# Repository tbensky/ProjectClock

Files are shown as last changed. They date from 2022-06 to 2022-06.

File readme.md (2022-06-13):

# Mechanical Clock Escapement

The following directions illustrate a step by step plan to building a working, gravity-driven mechanical clock escapement.

Clock Escapement

([See on Youtube](https://youtube.com/shorts/22PK3F16n6g]))

## Parts

The escapement can be constructed using the parts shown here.

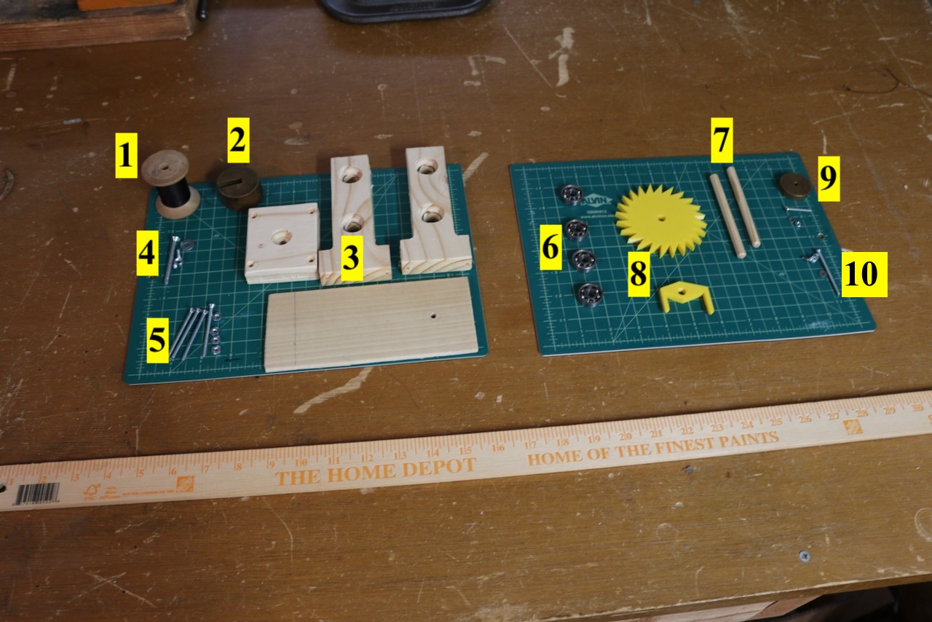
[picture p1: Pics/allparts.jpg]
Parts


1. Some string used for the drive weight.

2. Some weight to drive the escapement. This escapement runs on about 200 g (0.5 lbs) of weight (minimum). Shown is a piece of brass, but anything can be used.

3. Parts cut from some solid material (wood, plastic, composite, etc.); see Frame section below.

4. #10 screw with washer and wing nut.

5. 4, 2" long #6 screws with washers and nuts.

6. 4 fidget spinner bearings.  Outer diameter is 22 mm, inner diameter (of hole) is 8 mm, and thickness is 7 mm. These are very common bearings and sizes. (See Amazon and eBay.)

7. Two 5/16" (7.9 mm) (dia.) wooden dowels cut to 4" long. The dowels should be able to slide into the (8 mm) holes on the bearings.

8. 3D printed escape wheel and anchor (see below).

9. 50 g (0.1 lb) weight to be attached to the swinging end of the pendulum. This helps it keep swinging. Can be anything as long as it has a bit of mass.

10. 1, 2" long #4 screw with washer and wing nut (this is for clamping the pendulum onto the escape wheel axis; see below).

## Frame

To start, you'll have to CNC four parts out of some solid material like wood (manual cutting is possible). Any machinable wood, plastic or composite will work too (like MDF, Delrin, acrylic, etc). The only condition is that your stock is a minimum of 0.28" (7 mm) in thickness.  We used pine (wood) planks used for shelving (from our local hardware store) that are about 0.8" thick. The material serves as the escapement frame, holding everything togetgher. 

The CAD (.DWG file) is in the CAD folder, and looks like this

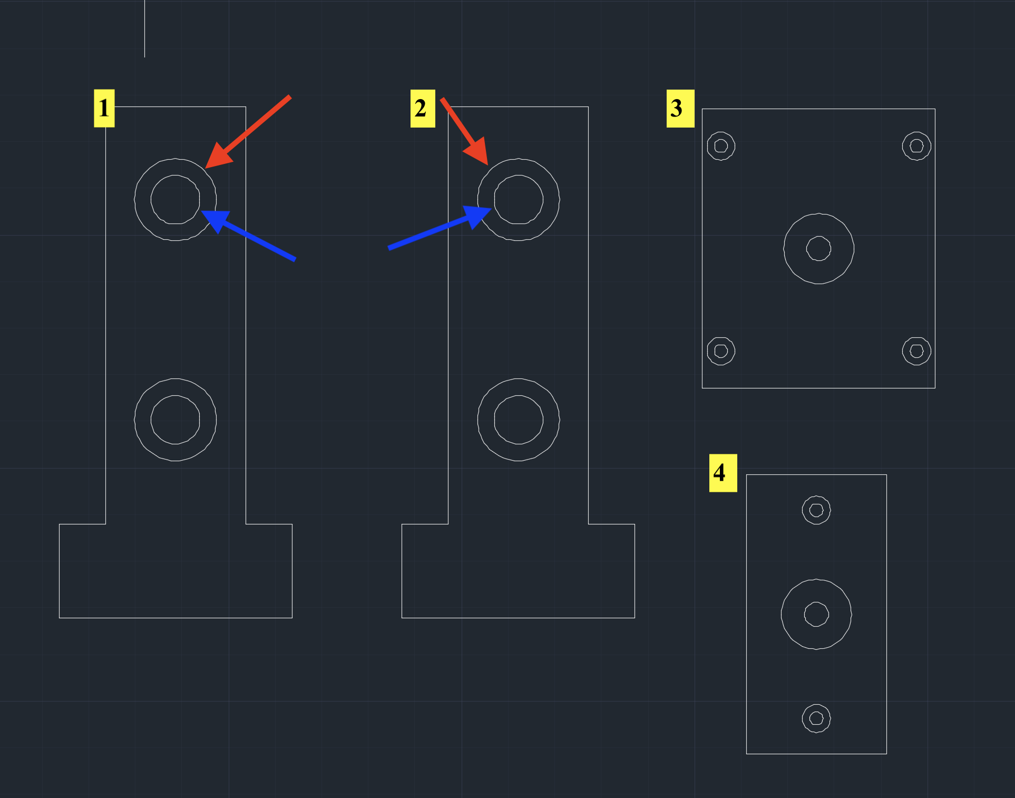
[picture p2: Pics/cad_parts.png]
CAD file


Parts 1 and 2 are the sides of the escapement frame. Part 3 is the base of the frame, and Part 2 is the top of the frame.  The circles pointed to by the red arrows are to be CNCed as "pockets cuts" to 0.2730" (7 mm) deep. The circles with the blue arrows are to be cut through.  The smaller (outer) circles on Parts 3 and 4 are also 0.1" deep pocket cuts, and serve as countersinks for #6 screw heads. The inner circles on Parts 3 and 4 are to be cut through.  The large circles at the center of Parts 3 and 4 are pocket cuts to about 1/2 the depth of your material. These are not critial to the escapement; they are meant to countersink a clamping bolt.  The inner center circles on these pieces are to be cut through.

We get good results using two cutting tools.  All pockets cuts on Parts 1, 2, 3 and 4 and the countersinks and through-holes on Parts 3 and 4 are first cut with a 1/8" end mill. Some precision is needed on the pocket cuts to hold the bearings snugly with just friction (and the 1/8" cutting tool seems to deliver on this). Everything else can be done with a 1/4" end mill. Use tabs on all parts. 

Our CNC simulation looks like this

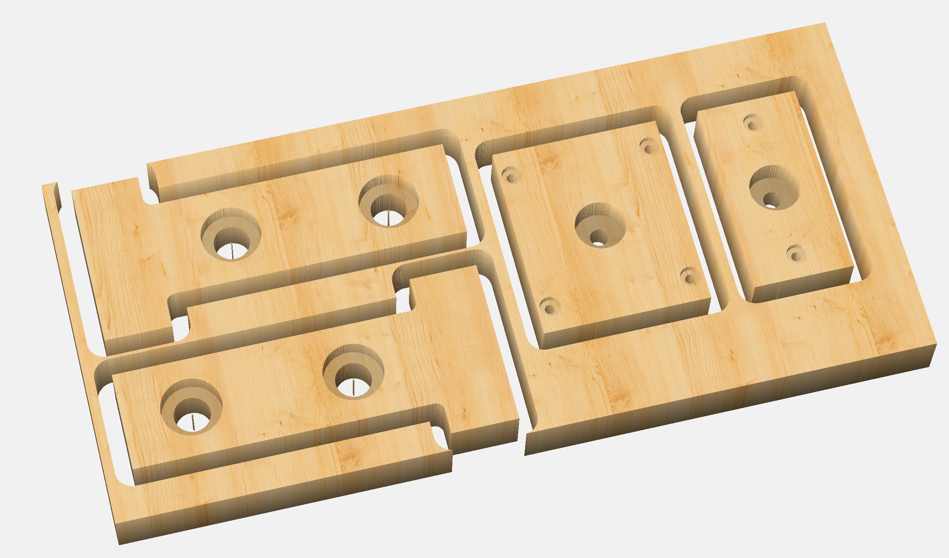
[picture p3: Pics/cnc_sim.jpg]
CNC simulation


We used a Shapeoko CNC from Carbide3D. For efficient material use, we used a 12"x5.5"x0.8" plank. Set the origin to the upper-left and clamps along the long edges of the board.  

### No CNC?

It's possible to make the frame without a CNC machine.  The only real need is to hold two pairs of bearings 2.36" apart center-to-center (+/- 0.01", escapements are finicky).  The bearings are 22 mm in diameter; holes to hold them can be made with an appropriately sized Forestner bit. Some sanding or firming up may be needed.

### Frame assembly

Once the frame pieces are ready, clamp (but do not glue) them together like this

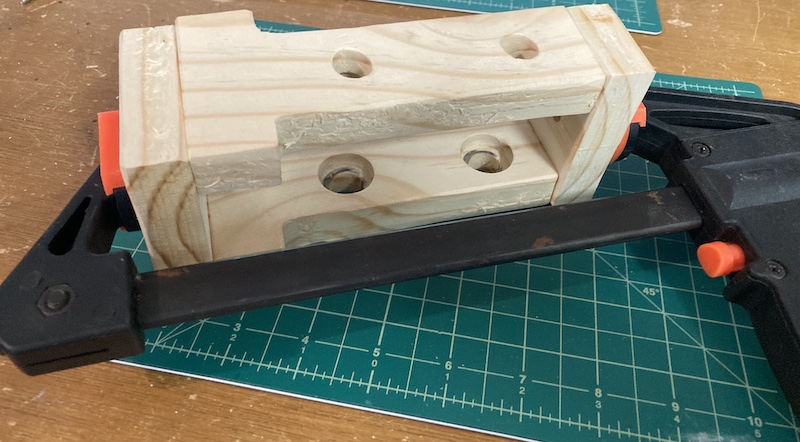
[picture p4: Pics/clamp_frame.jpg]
frame clamp


and be sure everything is squared up.  You are just clamping them here; do not apply any glue.  The pocket cuts that hold the bearings can face either inward or outward.

When secure, drill up through the four holes in the base, from the bottom of the base, up into both of the sides, like this

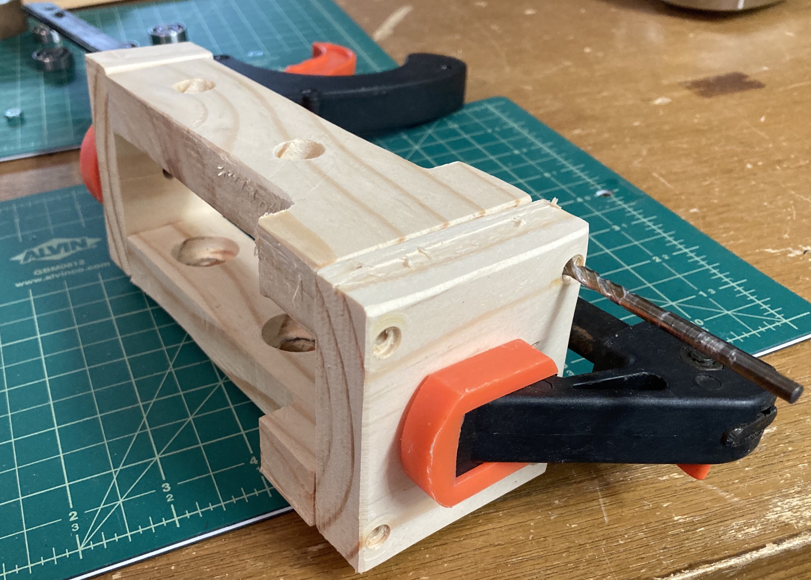
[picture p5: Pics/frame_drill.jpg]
frame clamp


Each hole should be able to accommodate one of the 4 #6 screws. We used a 5/32" drill bit. The screws are meant to hold the sides to the base and should sink nicely into the CNCed countersinks. The top isn't really used or important.  You can attach it to the escapement as a final step if you wish.

##  Escape wheel and anchor

The escape wheel (with 24 teeth) and the anchor look like this (on the way to a 3D printer):

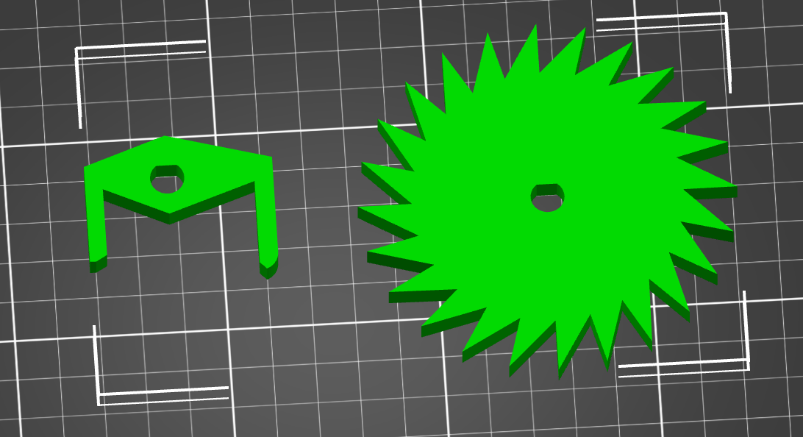
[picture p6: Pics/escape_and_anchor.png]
escape_anchor


We 3d printed these with PLA (STL files for them are in the STL folder), but they can be CNCed as well (see .dwg file in the Cad folder).   If CNCed, they should be cut on 1/4" thick stock. We've used wood, acrylic and Delrin. If anyone cuts them from Aluminum or Brass (or any metal), let us know (we'd love to see it). We recommend a 1/8" endmill.

Here's our 3D printed result.

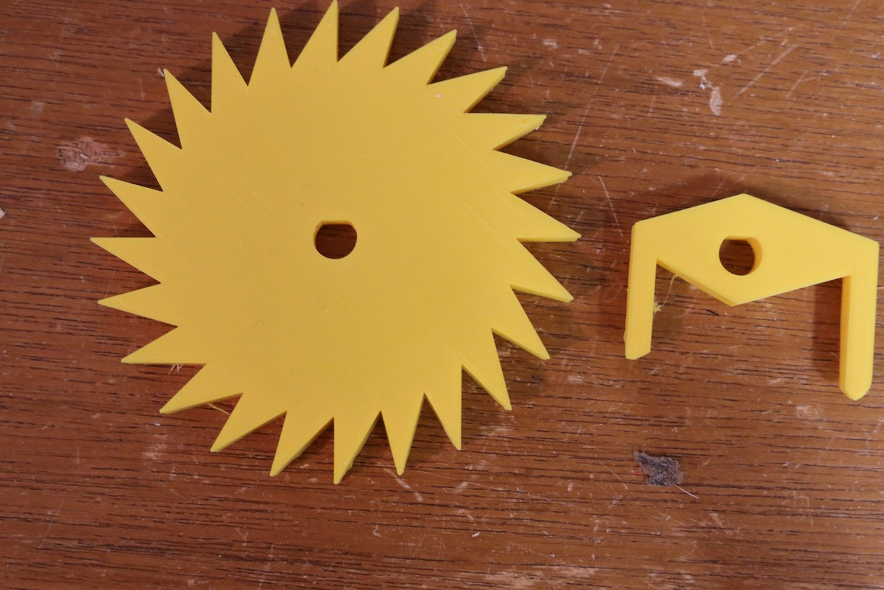
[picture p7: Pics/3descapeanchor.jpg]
escape_and_anchor


### No CNC or 3D printer?

If you trace the pattern onto a 1/4" wooden plank, you can try to cut out the escape wheel and anchor with a scroll saw, but it is difficult to get parts that will work. Escapements are finicky and the 3D printed parts here are good to 0.1 mm or so. With a scroll saw, you'll get the parts, but the escapement may not work no matter how hard you try.  Mounting holes for each can be made with a 7/16" drill bit. 

### Mounting the escape wheel and anchor

The escape wheel and anchor are to be mounted onto the 7/16" x 4" wooden dowels.  As you can tell, the wheel and anchor are keyed, so you'll have to sand down a flat section on the dowels to allow them to fit into the holes on either.  Sand carefully, as this should be a very snug fit. We used Gorilla Glue two-part epoxy to fasten the two.

Important: Do not center the escape wheel or anchor on each's dowel. Place each about 2.5" from either end as shown here. The asymmetry is so you can have the pendulum swing on one side of the escapement, and the weight fall on the other.

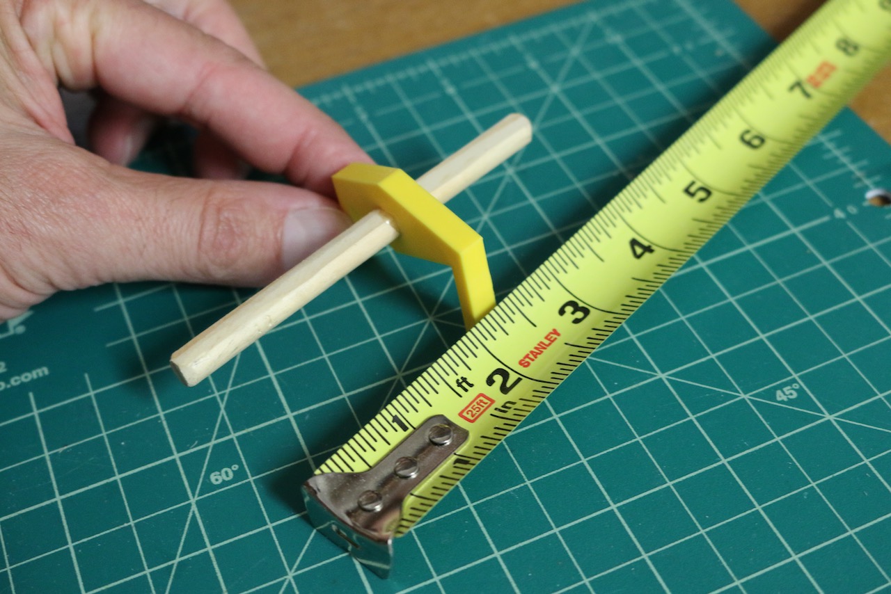
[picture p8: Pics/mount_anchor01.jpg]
escape_and_anchor


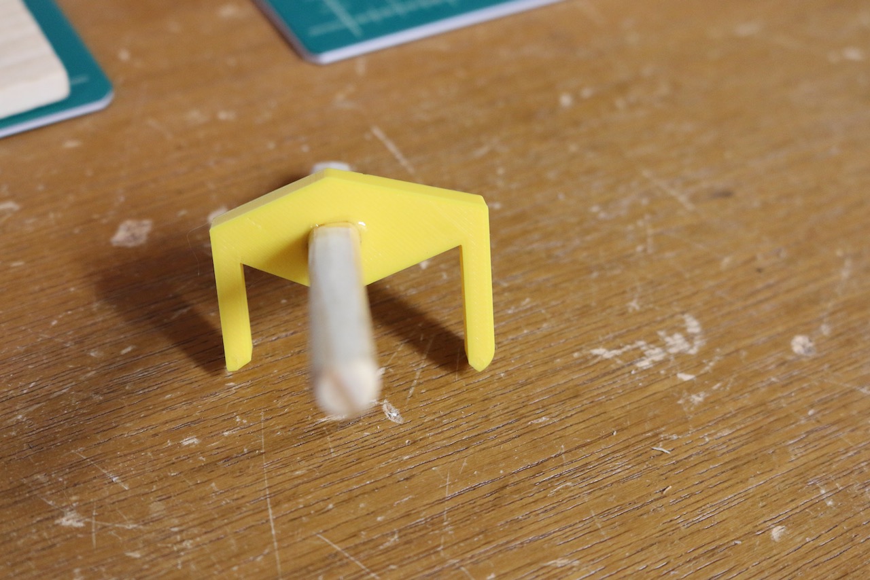
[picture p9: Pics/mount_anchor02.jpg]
escape_and_anchor


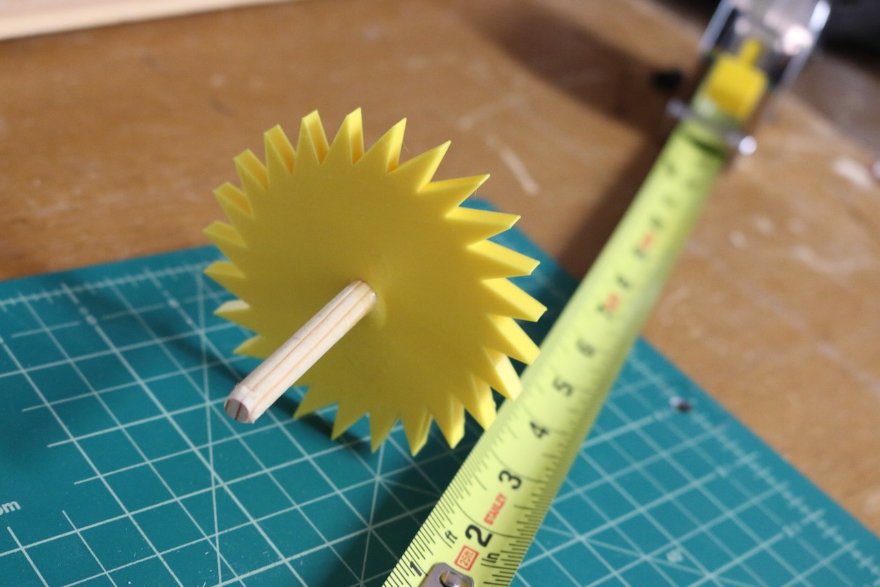
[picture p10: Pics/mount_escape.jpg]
escape_and_anchor


Near the tip of the long end of the dowel holding the escape wheel, drill a small radial hole through the dowel that you can thread a string through. (This will help later when attaching the drive weight.)

## Support

This piece is not critical, but allows for the escapement to be clamped over the end of a table while you're working on it.  

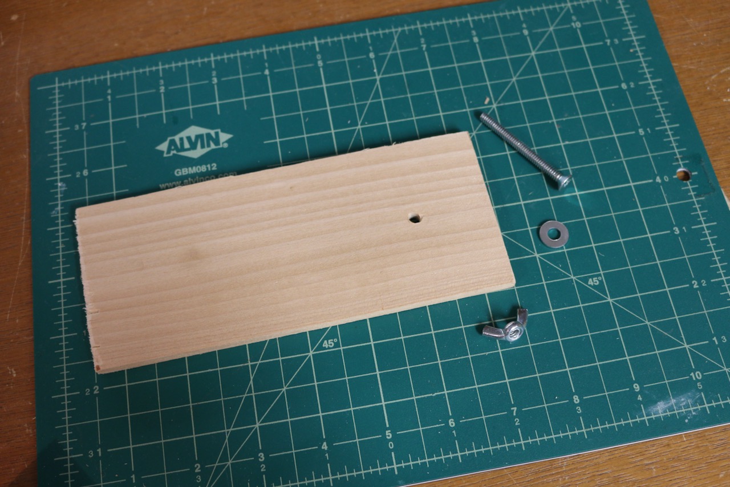
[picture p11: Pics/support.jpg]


We cut a 7"x3" by 1/4" thick piece of scrap and drilled a hole that can accommodate the #10 screw. The hole should be positioned so the thru hole in the wooden base of the escapement can be held at the end of the support by the screw. In use, it'll look like this

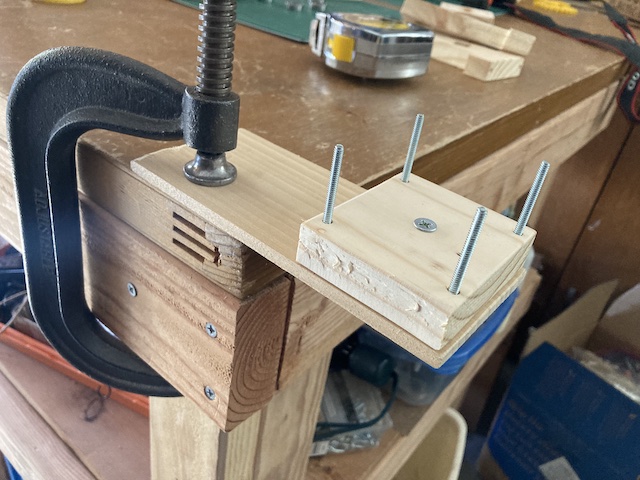
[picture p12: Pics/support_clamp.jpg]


## Pendulum

The pendulum is a yard stick from the hardware store (used for stirring paint). They work well, because they'll give your escapement a period of about 1 second, and tend to stay straight.

To start, on one end, drill a 5/16" hole about 1" from the end. Use a hand saw to cut a slot from the end of the pendulum to the hole itself, then sand the inner edges of the slot a bit
to give it some width, as shown here

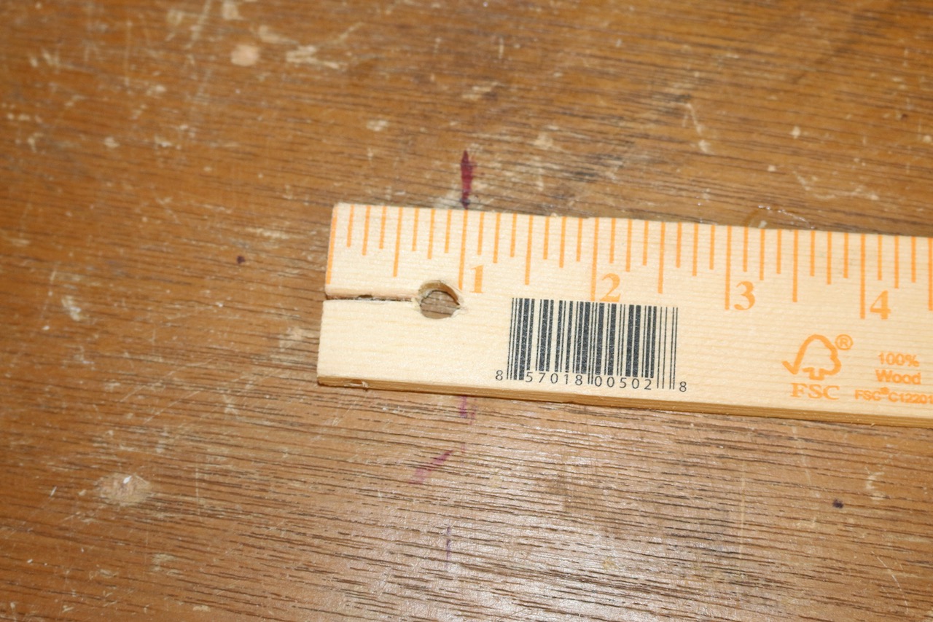
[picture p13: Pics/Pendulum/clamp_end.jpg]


Next, drill a hole suitable for a #4 screw transverse to the slot, like this

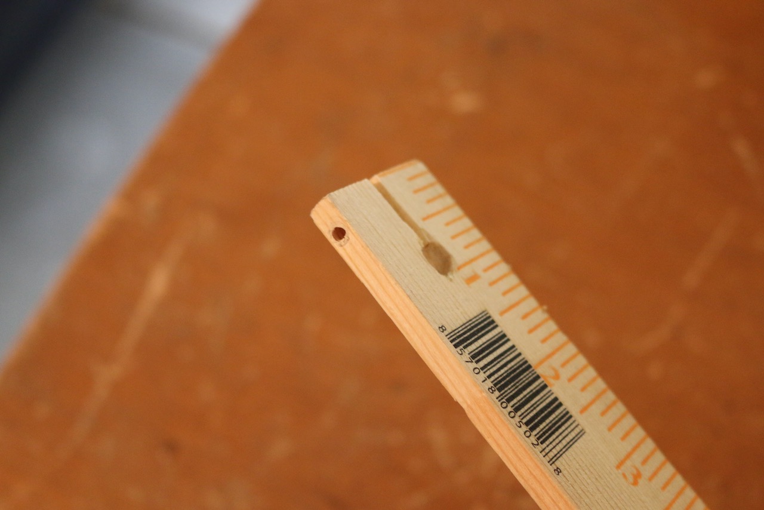
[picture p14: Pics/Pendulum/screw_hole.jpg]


(These steps might be reversed for better results; that is, drill the #4 transverse hole first.)

Next, insert the 2" long #4 screw with its wing nut.

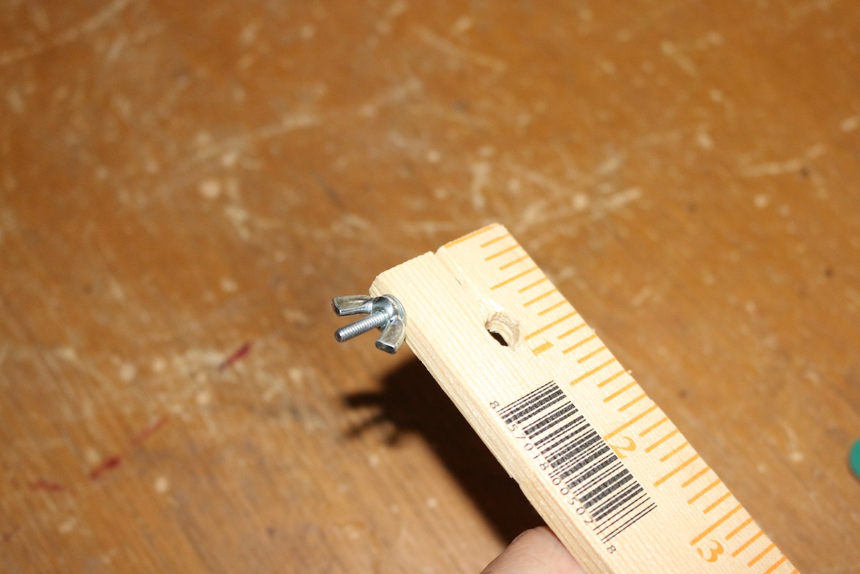
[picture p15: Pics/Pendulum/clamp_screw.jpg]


This will allow you to clamp the pendulum onto the anchor's dowel/axle.

On the other end of the pendulum, drill a hole so you can mount a small weight onto the end of the pedulum. This is not critical (do whatever is needed). Ours looks like this

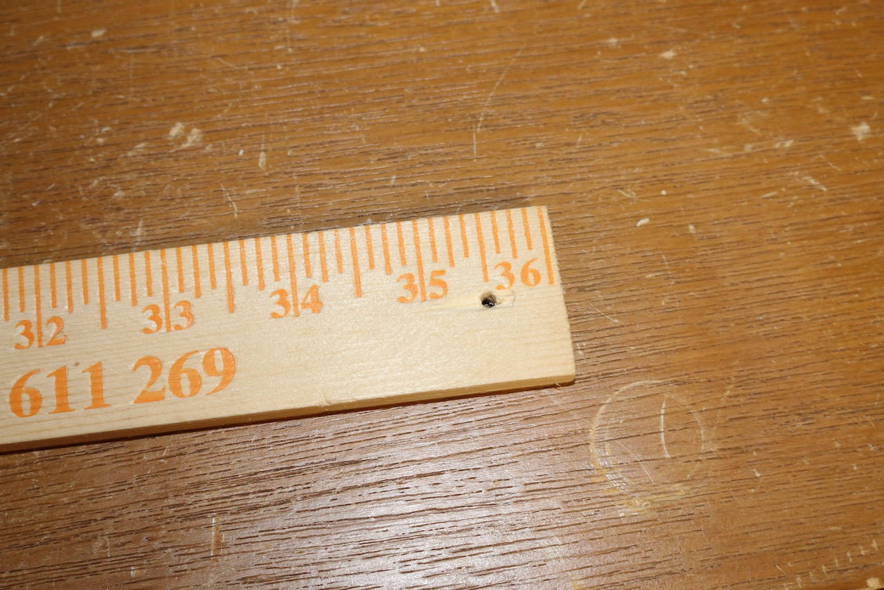
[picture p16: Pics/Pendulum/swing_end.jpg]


and

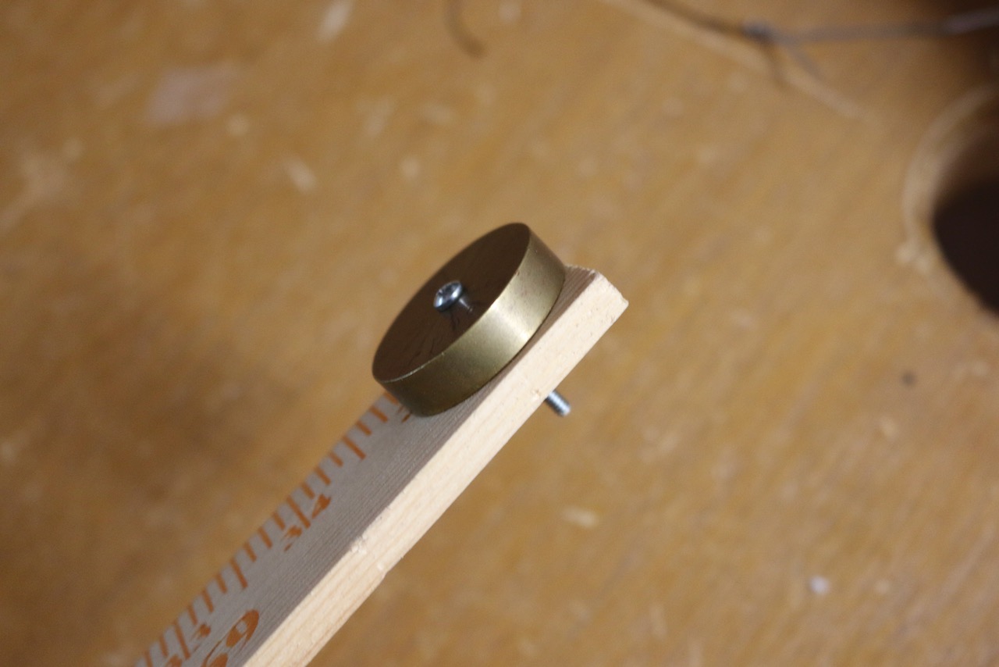
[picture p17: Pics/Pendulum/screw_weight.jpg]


A small stack of washers has also worked for this. The mass at the end of the rod gives the swinging pendulum some good angular momentum, which helps to keep the escapement running. 

# Assembly

Now, push the bearings into the holes on the frame. The bearings should fit snugly, but not too tight. If the bearings are pushed on too much by the wood, they won't turn freely. You should be
able to push them into the frame fairly easily with just your fingers (no hammers or forcing/pounding).

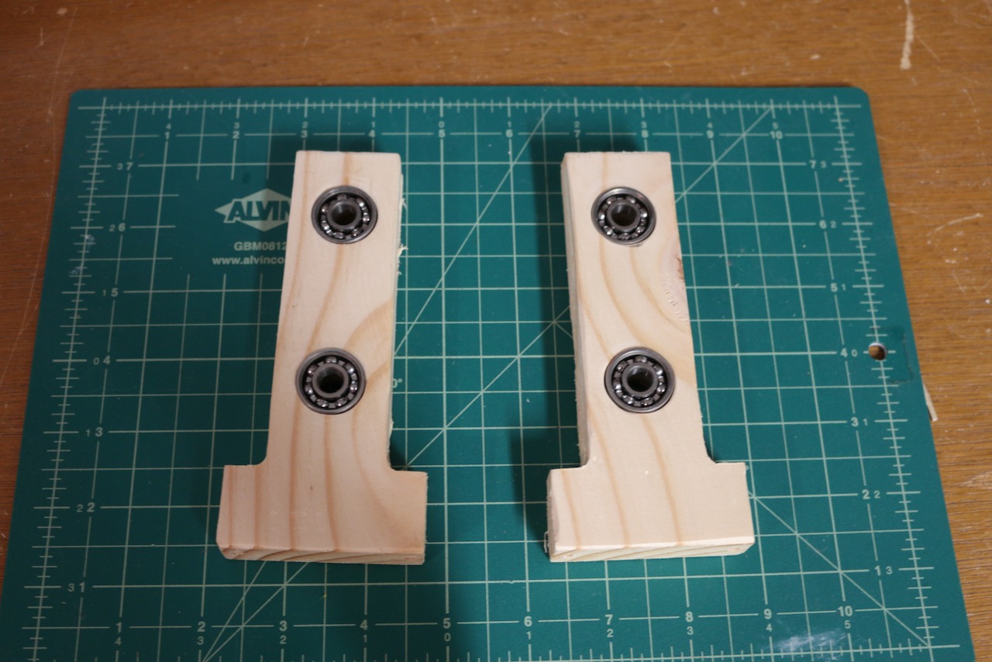
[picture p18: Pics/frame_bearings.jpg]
bearings in frame


Now, juggling everything, work to assemble your parts like this.

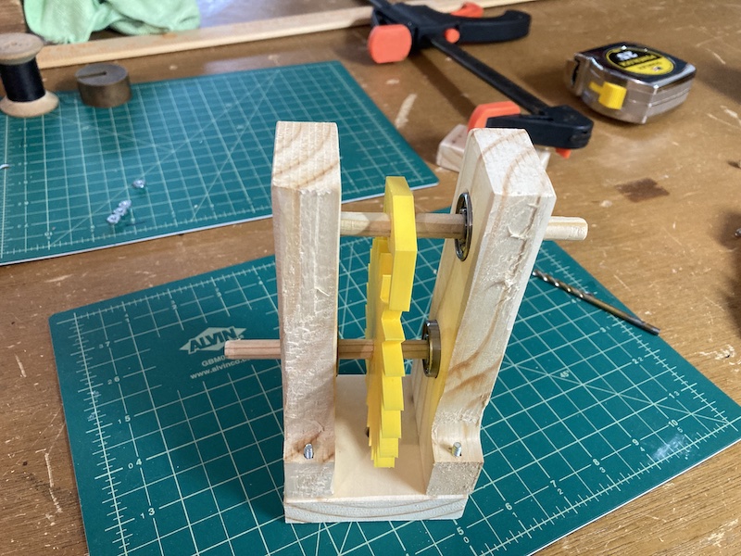
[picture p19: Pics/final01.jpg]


The anchor and escape wheel should overlap horizontally.  Also, be sure the longer end of the anchor goes out one side, and the longer end of the escape wheel goes out the other.

You can now mount the assembly on the support board, fastening it with the #10 screw and wing nut.  Clamp it to a table so the escapement is over the edge like this.

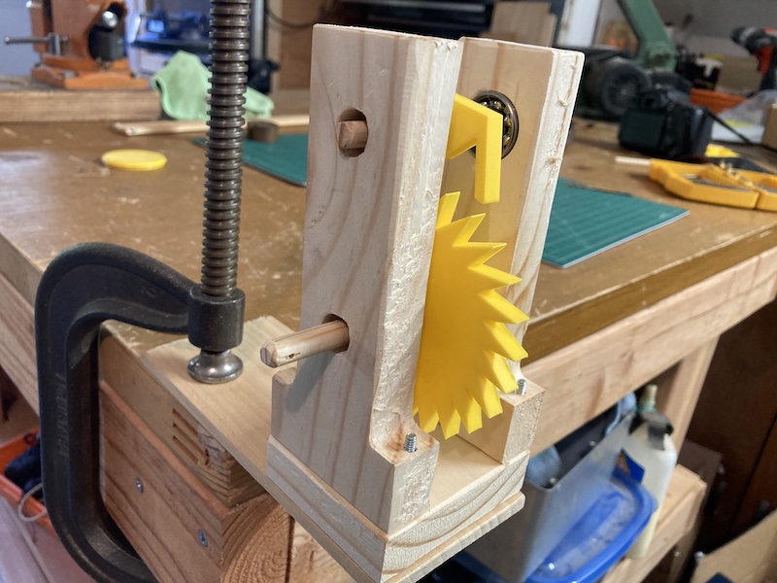
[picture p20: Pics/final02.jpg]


Put the nuts onto the #6 screws, to tighten the base to the sides of the escapement.

# Quick escapement tutorial

You're about ready to install the pendulum and drive weight and get your escapement running. Before that, let's take a quick look at how escapements are supposed to work.

First, the anchor and escape wheel need to be able to come into contact with one another. Further, the amount of contact they have and when they contact are somewhat critical. The shape
of both the anchor and escape wheel are important as well.

This animation from [here](https://en.wikipedia.org/wiki/Escapement) is very helpful and instructive

esccapement

Watch it for a while and see how the anchor and escape wheel teeth interact. We need to reproduce some of this action here.

In this figure, our anchor and escape wheel in close proximity. (As you look through these figures, note that for this escapement, the escape wheel always rotates clockwise due to the drive weight, and the anchor will always oscillate back and forth.)

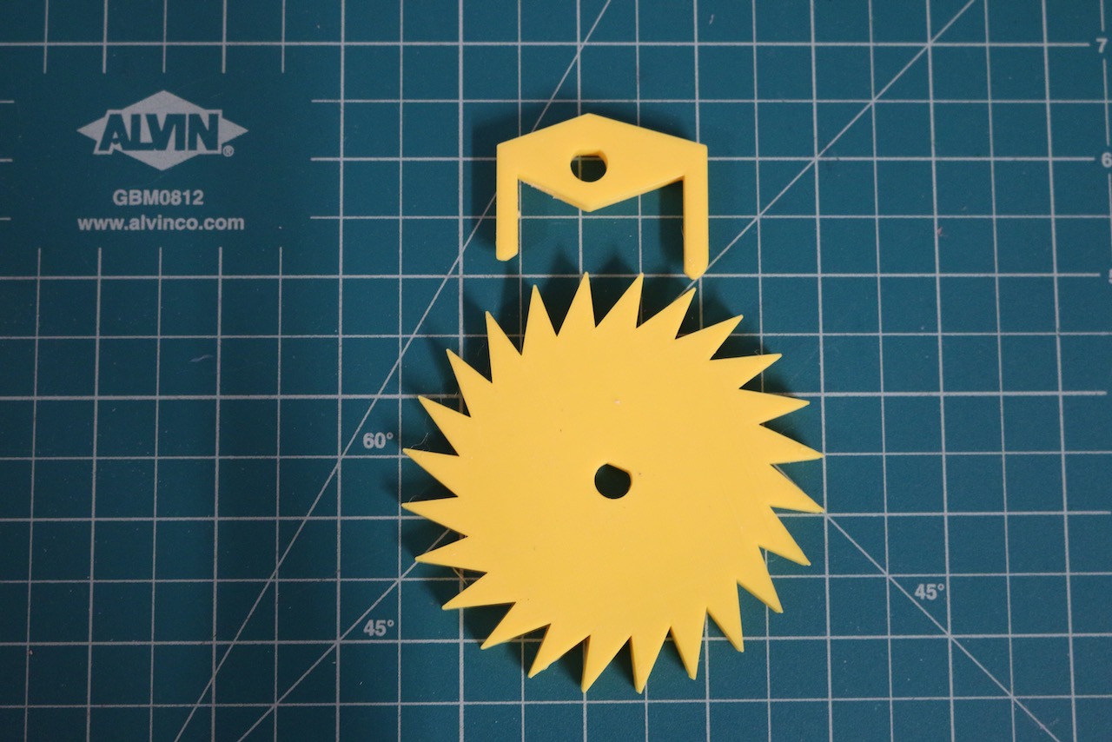
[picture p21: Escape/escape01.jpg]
escapement


But the escape wheel to anchor distance is too far apart for any working escapement. You'd have to have a very large pendulum swing angle to get the anchor's pallets to engage with the escape wheel.

Let's lower the anchor some like this

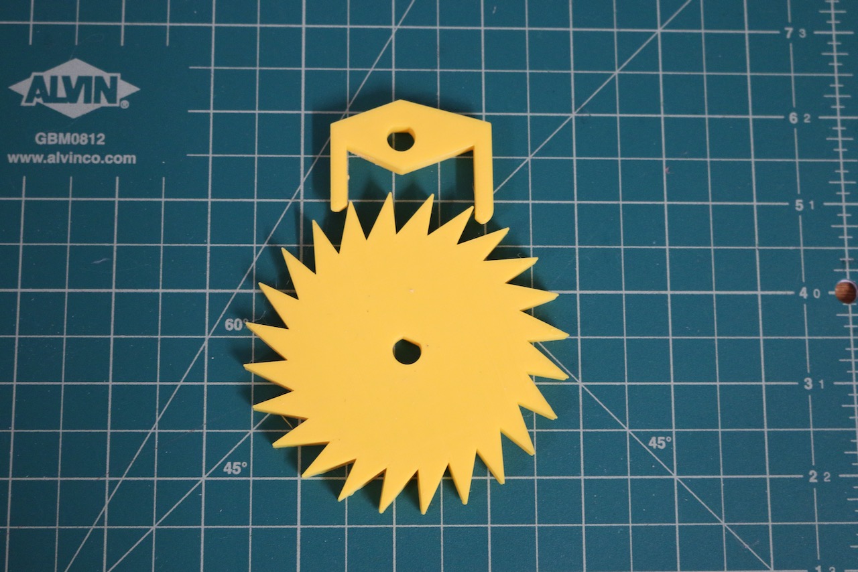
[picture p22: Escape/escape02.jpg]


Now, imagine the anchor oscillating (as driven by the pendulum), like this

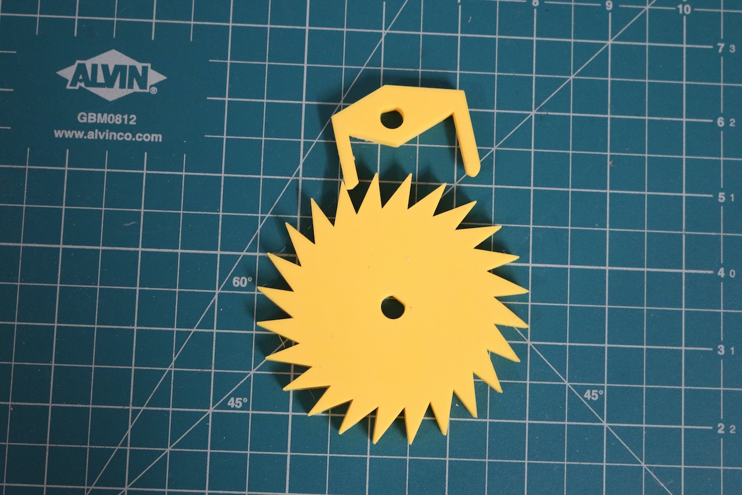
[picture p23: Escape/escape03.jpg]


See the contact? This stops the escape wheel from spinning. The sound of the contact will be a "tick" for the clock.

Then back again.

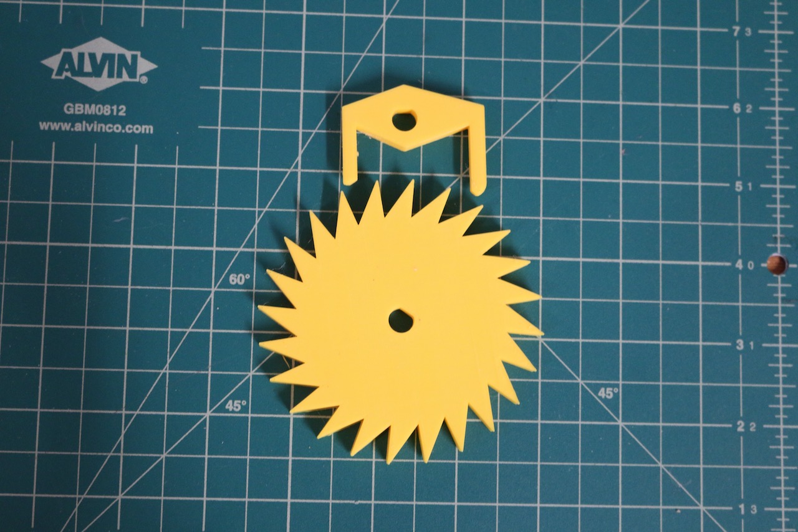
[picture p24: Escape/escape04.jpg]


Here there is no contact and the escape wheel is free to spin (but it won't get very far) because very soon, contact is made again like this:

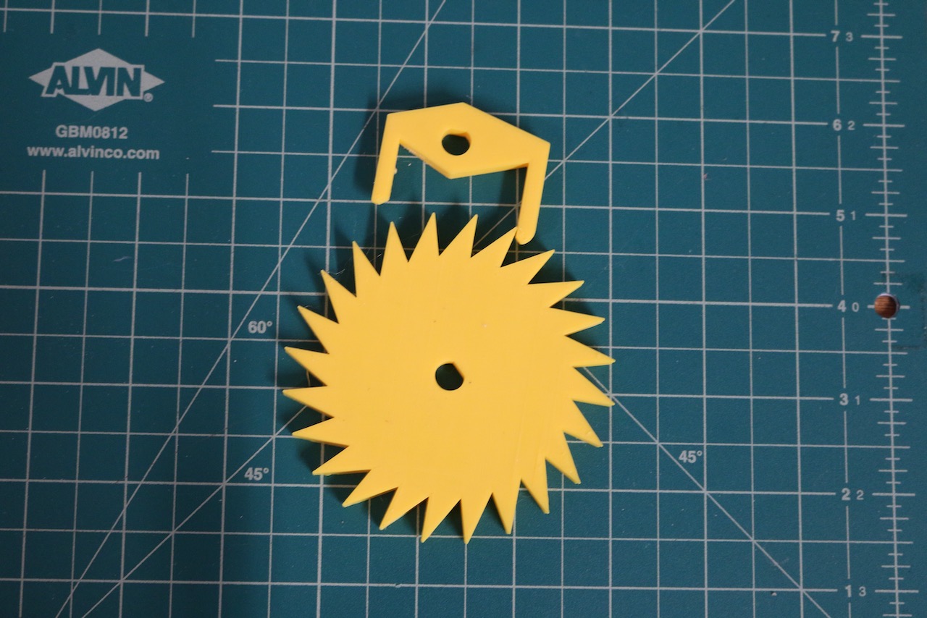
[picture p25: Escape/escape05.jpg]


This will once again stop the escape wheel again and make the "tock" sound.

It is difficult to design an escapement.  It is not enough to simply periodically stop the escape wheel. The pallets have to be shaped so that the releases (after the contact) can give the pendulum a knudge by the escape wheel with each release. This puts a bit of energy into the pendulum, to keep it swinging.

Here, by trial and error, with adjusting surfaces to $\approx 1$ mm, you can see how the escape wheel tooth slides off of the anchor, in a way that gives a little kick
to the pendulum.

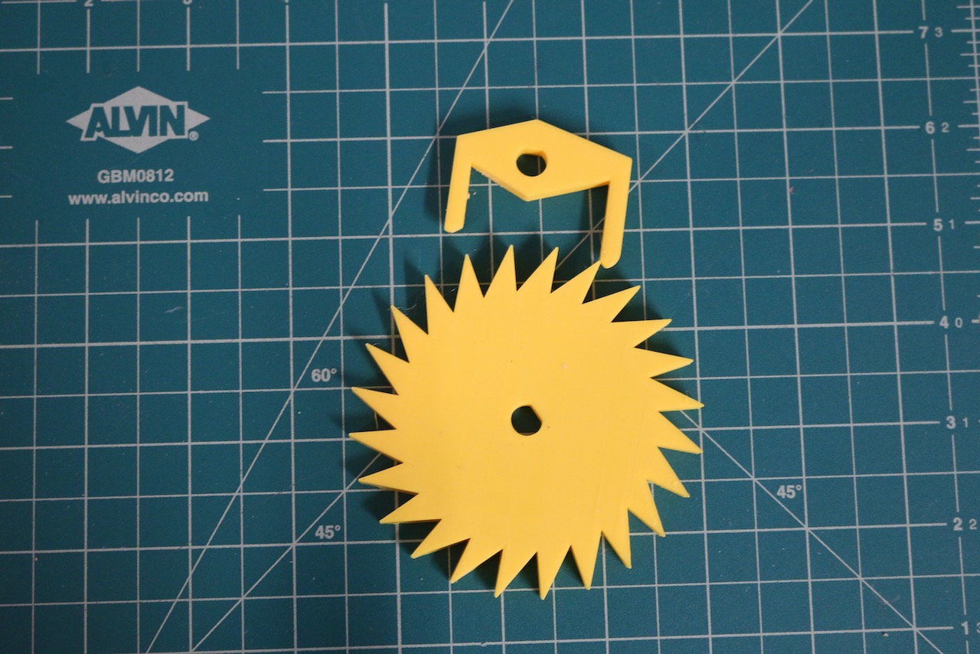
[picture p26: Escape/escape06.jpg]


When the left pallet of the anchor hits the escape wheel, it's a dead stop, with very little energy transfer back to the pendulum.  The right pallet however, after it stops the crown wheel, allows the tooth to slide off of it, along its contours to impart some energy into the pendulum. There are infinite variations of this, and it's quite interesting to study. (If you ever make it to London, England, there are 100s of escapements to watch in local museums.)  

The escapement here was developed by painstakingly watching non-working anchors (we made) for places where they jam up, stopping the escapement. When found, some CAD work and refabrication was done to reshape the anchor's surface to remove such jam points. The anchor design here is one that finally worked.

In this escapement, all of the distances and sizes are workable. That is, the bearing center-to-center distances (the 2.36" above), and the shapes of the escape wheel and anchor are all tied together. If for example, the bearing to bearing distance is too large or small, the anchor may not engage the crown wheel properly. Thus, this escapement design is reduced down to only one possible adjustment (see below).

# Installing the pendulum and drive weight

You are now ready to install the pendulum and drive weight.

First the pendulum, which just slides and clamps onto the axle of the anchor. Get it snug for now, but do not tighten the clamp screw.

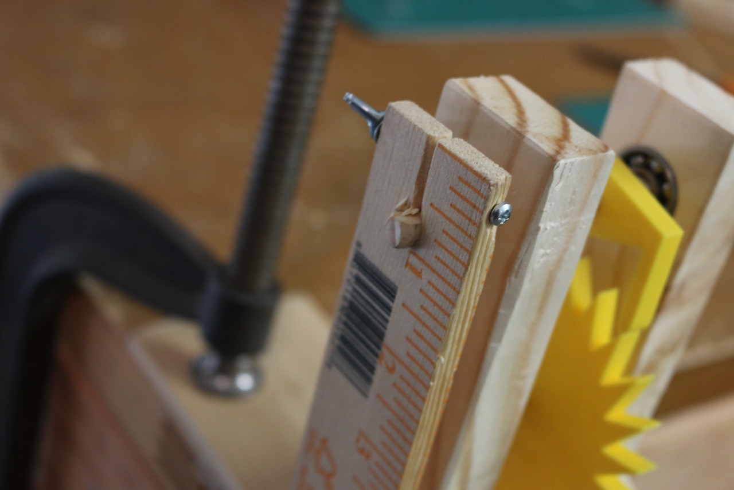
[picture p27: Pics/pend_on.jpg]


Next, tie some string through the hole on the end of the escape wheel's axle.

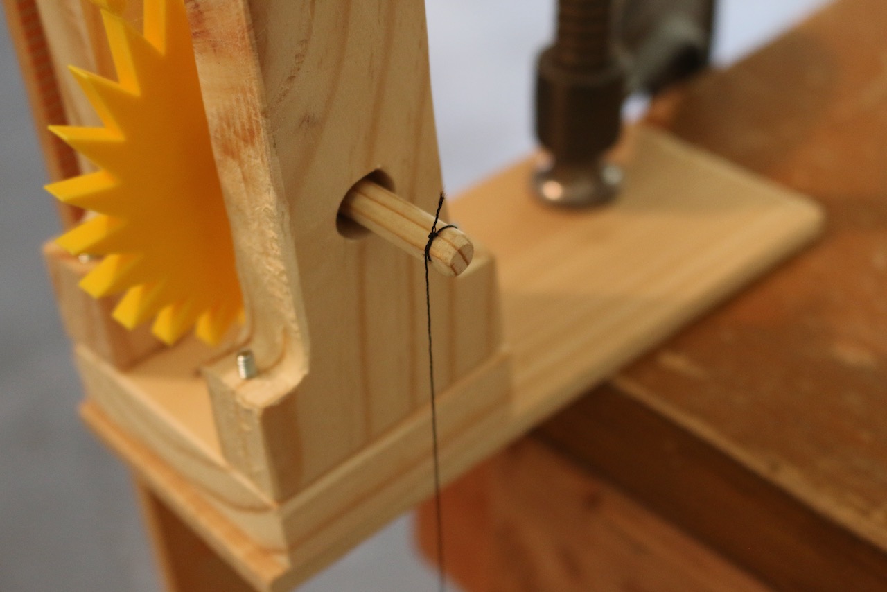
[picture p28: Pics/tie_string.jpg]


By whatever means, also attach your drive weight (at least 200g or 0.5 lbs) to the free end of the string.

Lastly, wind the string around the axle so it'll turn the escape wheel clockwise, as shown here.

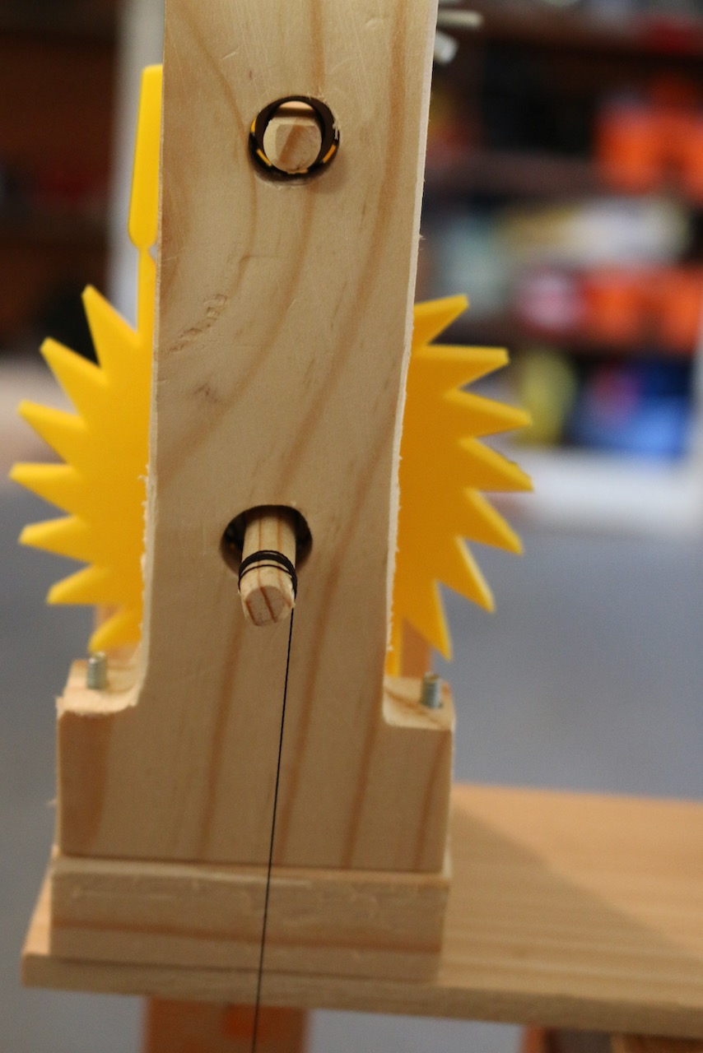
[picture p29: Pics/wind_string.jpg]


# Starting your escapement

Now, give the pendulum a small pull in one direction or the other. Hopefully the escapement will start ticking and tocking a few times. Initially, it'll likely stop after a few ticks and tocks though. 

As mentioned, since all part shapes and relative orientations are all set, there is only one adjustment: the angle the pendulum makes versus the angle of the anchor.

In sum, you'll want to adjust the angle between the pendulum and the apex point on the anchor, shown here.

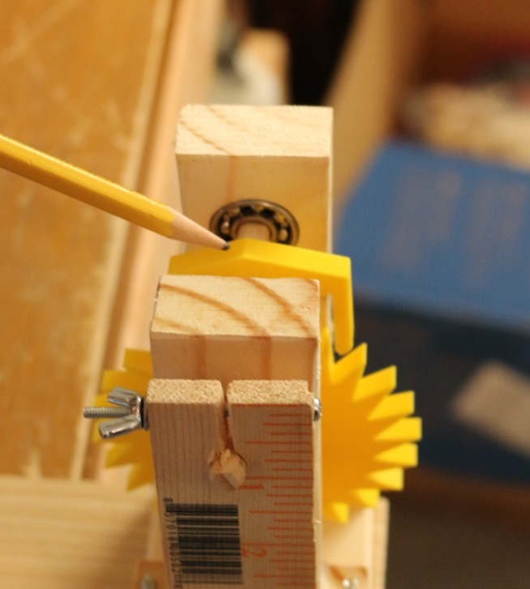
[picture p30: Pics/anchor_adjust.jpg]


## Tips

* We find if the apex point is straight up when the pendulum is vertical, then the escapement should run.

* If the escapement keeps stopping, watch it as it tries run, reviewing the "escapement tutorial" above.  

* In particular, watch the drops and releases of the anchor's pallets, into and out of the escapement wheel's teeth. The drop should be minimal for a given pallet, and the anchor's motion should be as symmetrical as possible.

* Listen to the escapement. The tick and tock sounds should be of similar volume. If one sounds heavier or louder than the other, then adjust the pendulum/anchor orientation.

* You can always add weight to the drive weight, but you'll want to optimize this, and run your escapement with as minimal weight as possible.

# More information

* The author got interested in making clocks in the context of the history of navigational technology.  He's written all about time and clocks in Part II of [this book](https://www.amazon.com/Longitude-Time-Navigation-Tom-Bensky-ebook/dp/B00HKMCE0A/).

* This escapement has been written up [here](https://github.com/tbensky/ProjectClock/blob/main/Paper/BHJ_June2019.pdf).

* [This video](https://www.youtube.com/watch?v=B8Y146v8HxE) and the series that follows on making a clock is simply incredible.

# Other's builds

If you build this escapement, send a pull request in this document, with a link to a Youtube video of your escapement. We'd love to see it and share it here!

* Brian T. said:

> Thanks so much for posting your plans and detailed
instructions for your escapement.I built my escapement following your
instructions. I used a small bandsaw to cut the wheel and made 4 of
them. I used a 1 once knob I had laying around for the weight. Only 1 of
my escapement wheels ran without skipping or locking but I consider that
pretty good. My escapement ran for about 3 minutes and 45 seconds with a
fall of about 3 feet. I'm thinking of making some more wheels and a
sliding bob for the pendulum along with a 3-fall pulley system to do
some experimenting with getting my escapement to run longer. I have
found lots of interesting stuff on-line about making escapements but I
found yours most helpful in getting one actually built. [Here’s a video
of his version](https://www.dropbox.com/s/bihw26psfokd77d/clock%20escapement%202015-08-30.mp4?dl=0).

* uprc2005 said:
> hi, we tried to replicate your nice escapement design, thanks for the inspiration. [Watch it here](https://youtu.be/gZWi7g5TwoY).

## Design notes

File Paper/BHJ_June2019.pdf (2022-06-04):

30 | HOROLOGICAL JOURNAL | June 2019

Introduction
My university offers general education classes themed in how scientific, mathematical, and technological knowledge can be used to ‘solve societal problems’. About ten years ago, I developed a course with this theme, based upon pre-1800 navigation, timekeeping and the ‘longitude problem’ of that era. I teach it both at my university and periodically, in London, England (due to the city's roots in the history of navigation and timekeeping). I wanted a final project for my students and since timekeeping is of critical importance, I decided to have them try to build a working mechanical clock escapement.
There would be many constraints, particularly for the navigation and clock making class that I teach in London. Resources here are more limited than in my ‘normal’ class in California. No workshop or power tools would be available, the cost would have to be low, and the entire activity portable. It would need to provide ten groups of two or three (largely uninitiated) students with a high likelihood of clock building success, after no more than a few hours of work. At least some flexibility in the design would be desirable. I decided that an escapement kit the students could assemble and ‘fiddle with’ was needed. But what would it be?
Work with scissors, cardboard and tape seemed messy and unpredictable, and kits¹
, as well as Lego escapements on YouTube seemed too linear and simplistic. Most others, however spectacular, were too complicated to prepare or would require too much time to assemble.²
At about the same time, I was becoming interested in digital fabrication with CNC machines.³

So, with an escapement kit as motivation, I purchased a Shapeoko CNC machine from Carbide3D, for use in my home workshop, and set forth to see what sort of escapement I could make with it.⁴

Wooden Escapement Kit
A pendulum driving an anchor escapement made entirely from wood seemed most appropriate to ease students into this. The pendulum would be a yard (or metre) stick, as they are readily available (abroad), tend to stay straight, and would deliver a workable two-second period. After experimenting with the Shapeoko, ¹

∕4 in thick cherry wood would serve as the stock for the escape wheel and anchor.
Many escapements were studied: in books, online and in London museums. I was drawn to a book by James Rudolph, on building a paper clock.⁵

I wasn't going to use paper, but Rudolph's book had a tested escapement design that seemed to be based on straightforward geometry, so I began to work his patterns for an escape wheel and anchor into CNC ready form.
Preparing a shape to be cut by a CNC machine requires one to produce a ‘tool path’, that instructs the CNC where to move the spinning cutter relative to the stock in x,y,z planes.

In this work, the tool path is always tied to lines of a 2D figure. The third dimension will come simply from the thickness of the stock. Typically, many passes are made along the lines by the CNC, until a desired cutting depth is reached. Although the Shapeoko comes with software called Carbide Create, it wasn’t sophisticated enough to design an escape wheel, so AutoCAD was used instead.⁶

The Escape Wheel
To start designing Rudolph’s 24-tooth escape wheel, two circles of diameter 3.5in and 2.5in were drawn co-axial with each other and a 5

∕16 in center hole, Figure 1. A single tooth near the top is shown completed, as aided by using an adjacent pair of 24 total diameters shown for the larger circle. With all teeth completed, the diameter portions within the smaller circle were removed, as were the two original circles, Figure 2. This file is now imported into Carbide Create. This allows one to set up the tool paths, and eventually simulate the design, Figure 3. The software also generates G-code, which is what actually runs the CNC machine, resulting in the escape wheel in Figure 4, after about 20 minutes of cutting.

The Anchor – Part A
Problems arose quickly with Rudolph’s anchor. The escape wheel was fitted with an arbor (a 5
∕16 in dowel) and mounted
in a roller bearing, with a drive weight tied around the arbor. The anchor, whose arbor was also mounted in a bearing and attached to the pendulum, was positioned so it could engage the teeth of the wheel. With this, the escapement simply would not run, no matter what was tried. Despite this discouragement, an escapement prototype was evolving that could be studied and iterated upon, owing to the power of the software and CNC combination. Many bleary-eyed hours were spent staring at the interaction between the anchor and escape wheel teeth, and quite a lot was being learned.
It became clear that the observations and adaptations needed to produce a working anchor/escape wheel combination would be the focus of this kit. Thus, students would need to be able to make adjustments to provide the desired flexibility. This would either have to be in the centre distance between escape wheel and pallet arbors, or in just the anchor itself. Since the former is rather uninteresting, it was set to 2.36 in (6cm), and adjustments were built into the anchor itself. We now pause the discussion of the anchor, to look at the mounting hardware.

Mounting Hardware
The 5
∕16 in dowels used for arbors fortuitously form a good friction fit into common skateboard or fidget spinner bearings.⁷ With this in mind, front and back faces were designed from 0.8 in thick alder stock, with 0.440in recessed (or ‘pocket cut’ holes) to a depth of 0.273in to hold pairs of bearings for each

# A Wooden Escapement

# Developing a Kit for Instructional Use

## Thomas Bensky

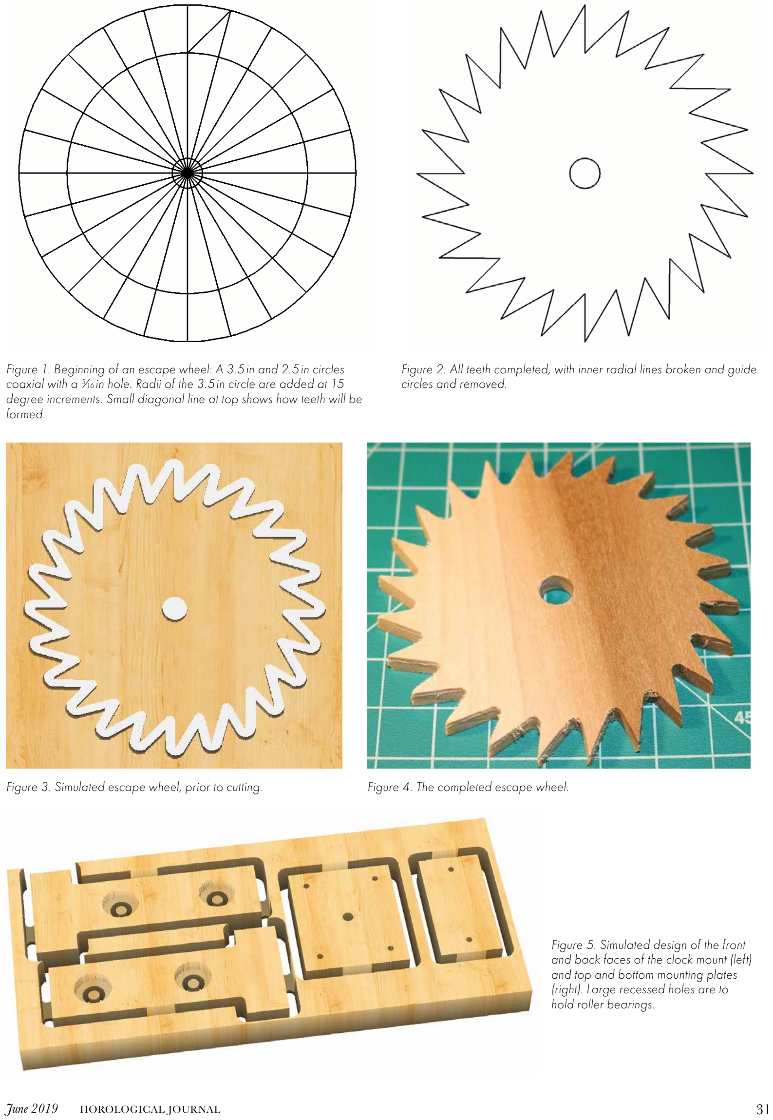
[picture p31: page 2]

June 2019 | HOROLOGICAL JOURNAL | 31

Figure 1. Beginning of an escape wheel: A 3.5 in and 2.5 in circles coaxial with a ⁵
⁄16 in hole. Radii of the 3.5 in circle are added at 15 degree increments. Small diagonal line at top shows how teeth will be formed.

Figure 2. All teeth completed, with inner radial lines broken and guide circles and removed.

Figure 3. Simulated escape wheel, prior to cutting. | Figure 4. The completed escape wheel.

Figure 5. Simulated design of the front and back faces of the clock mount (left) and top and bottom mounting plates (right). Large recessed holes are to hold roller bearings.

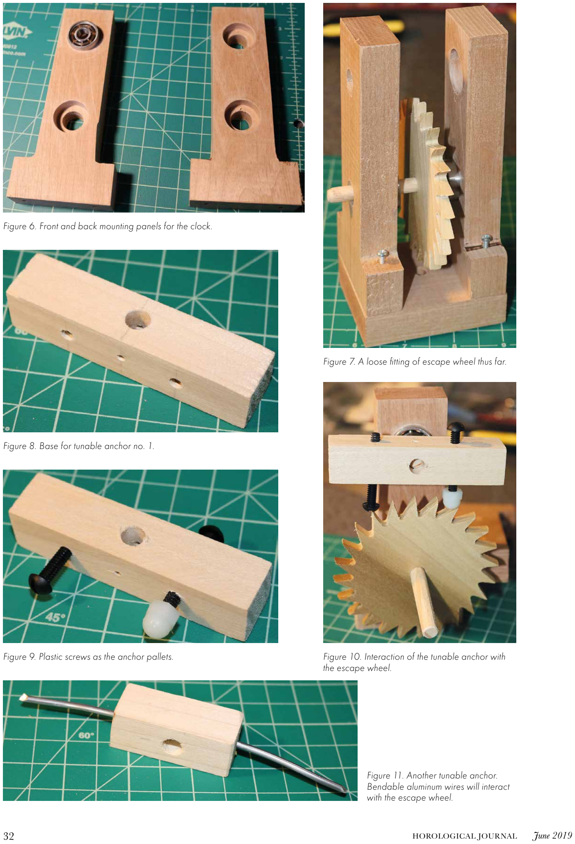
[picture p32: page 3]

Figure 7. A loose fitting of escape wheel thus far.

Figure 8. Base for tunable anchor no. 1.

Figure 9. Plastic screws as the anchor pallets. | Figure 10. Interaction of the tunable anchor with the escape wheel.

Figure 11. Another tunable anchor. Bendable aluminum wires will interact with the escape wheel.

Figure 6. Front and back mounting panels for the clock.

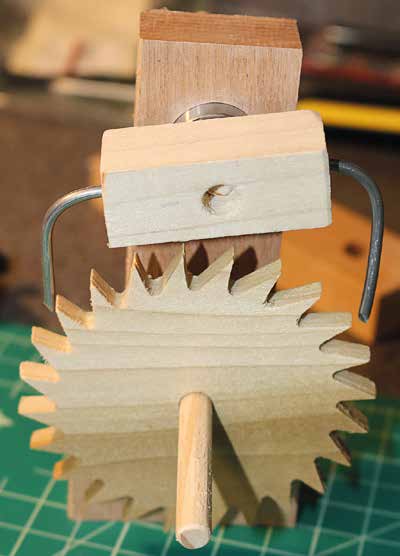
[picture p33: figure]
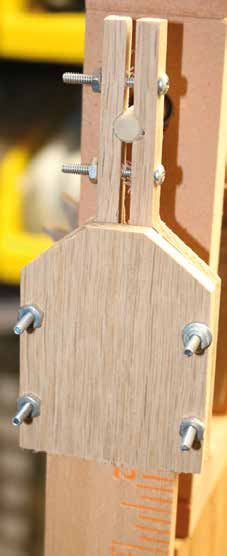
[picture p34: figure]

end of both the anchor and escape wheel arbors, as shown in Figure 5, by the pair on the left.
The rectangular pieces to the right in this figure are the top and bottom of the frame, with the small holes being no. 6 screw holes that will hold the frame together (no glue is needed).*

As shown in Figure 6, bearings are pushed into the pocket holes. Bringing everything together in a loose fit is shown in Figure 7. The arbor and bearings for the anchor are mounted (not shown) in the upper pair of opposing pockets above the escape wheel.

The Anchor – Part B
Lacking a working anchor, and bothered by little understanding between requirements for the escape wheel versus anchor geometries, a YouTube video by user Clickspring helped me to move this work forwards.⁸

It indicated how
often the escape wheel/anchor interaction step is a ‘subjective process’, requiring a bit of repeated cutting and trying until it finally works. With this idea in mind, two adjustable anchor mechanisms were developed.

Adjustable Anchor 1
In the first anchor, 3

∕4 in × 3

∕4 in × 3.5 in stock was drilled with a 5

∕16 in centre hole to accommodate an arbor. On the perpendicular face, two tapped no.10–32 holes were made, separated by 1.6 in (4 cm), as shown in Figure 8. Plastic screws are shown installed in Figure 9 and with its interaction with the escape wheel in Figure 10.
This escapement will work after many adjustments, and the plastic screws are ideal for small amounts of sanding and shaping by the students.⁹

The orientation of the screws, including the optional use of smooth, rounded acorn nuts is

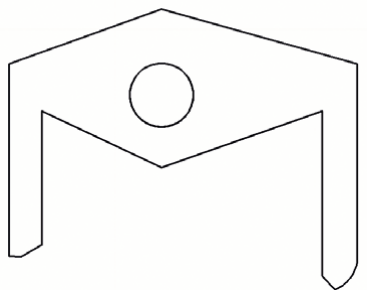
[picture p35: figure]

an open decision. The penetration depth of the screws into the teeth is readily adjusted by turning the screws in their threads. The stop and release action can also be easily studied.

Adjustable Anchor 2
In the second anchor, the same 3

∕4 in x 3

∕4 in stock, now 2in
long, was prepared as before, but now with two 3

∕16 in holes
on its outer longitudinal faces, to hold no. 9 gauge aluminum wire, Figure 11. This is mounted on the movement as shown in Figure 12.
The figure shows a common starting configuration that often results in at least a few initial ticks and tocks. The malleable nature of aluminum means pliers can be used to shape the wire into many possibilities until the escapement runs. Optimising, the ends of the wire can be fashioned into small loops, or smoothed with sandpaper to minimise friction.

Final Construction
Both adjustable anchors will result in a working escapement with a 50 gramme drive weight and a 100 gramme pendulum bob. The yardstick pendulum is mounted to the back of the anchor arbor using the clamping mechanism shown in Figure 12. The orientation of the pendulum, when vertical, with the angle of the anchor is a free parameter, adjusted by loosening the two top clamping screws. The yardstick itself is clamped between two wooden plates by the four screws (lower half of Figure 13). With the screws loose, the yardstick can be slid up and down, to adjust the timekeeping. A similar clamp is at the bottom of the yardstick to hold the bob.

A Fixed Anchor
Continued puzzlement over the logic between the escape wheel teeth and anchor geometries was beginning to work itself out. The most careful work during development of this kit was done with the aforementioned anchor no.1. The two screws were shaped and adjusted until the escapement had an

Figure 12. Assembly of the wire-based anchor into the escapement.

Figure 13. Wooden pendulum clamp on back of the
anchor's arbor. Yardstick
pendulum is just visible
extending downward. | Figure 15. The fixed anchor design.

* In the USA, screws are often named by a gauge number. The number 6 screw cited here is similar in size to an M3.5 screw, although of course the thread and head specifications would be quite different. –Tech. Ed.

Figure 14. Minimal interacting surfaces of the screw-based anchor. All dimensions are in inches.

1.5180in

0.7425in
0.8615in

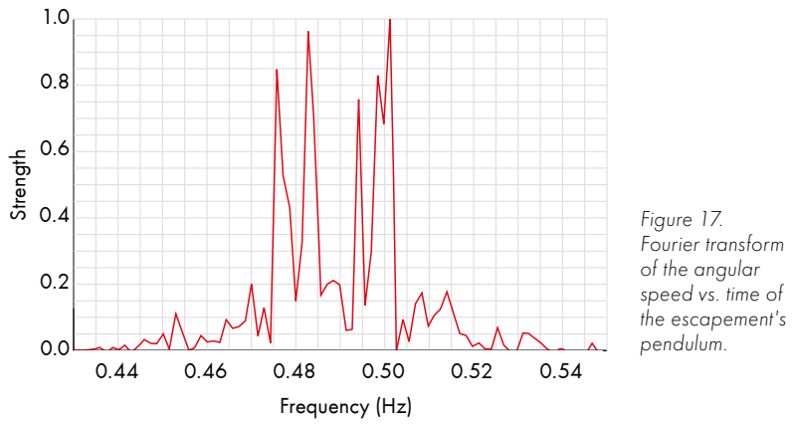
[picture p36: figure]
Figure 17. Fourier transform of the angular speed vs. time of the escapement's pendulum.; Strength; Frequency (Hz)
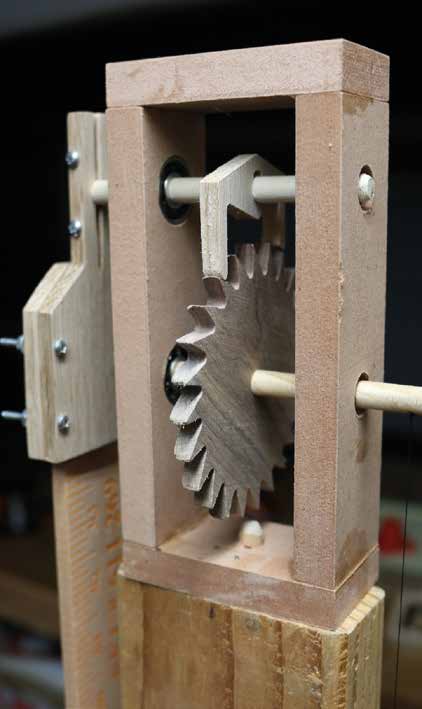
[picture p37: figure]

even and consistent running with minimal drop on the entry and exit sides.
The working anchor was then removed and measured, realising that only the surfaces interacting with the escape wheel needed to be reproduced, in their positions relative to the arbor mount. This is shown in Figure 14, and was definitely an epiphany moment in the puzzling process of designing an anchor. All that was needed now was to connect the open ends to make a CNC ready object, Figure 15. Indeed, the anchor worked almost immediately when inserted into the escapement. The only free parameter is its angle relative to the pendulum, which is adjusted as described above. This fixed anchor has since evolved through 15 small iterations, with continued careful study of its interaction with the escape wheel. In the iterations, the CNC design was altered down to one millimeter, which the Shapeoko happily accommodated. The final form of the escapement is shown in Figure 16; a slight push of the pendulum will start it running.

Escapement Performance
Three measurements were carried out to assess the escapement. The first was performed by attaching a small wireless gyroscope to the pendulum bob.¹⁰ This captured the angular speed of the pendulum versus time for approximately 1000 seconds (or 500 swings of the pendulum). The Fourier transform of this was taken and is shown in Figure 17. The escapement seems to be operating in five modes, near 0.5 Hertz (the frequency of a one metre pendulum). The Q of these modes ranges from 155 to 284.

In the second measurement, the pendulum was passed through a photogate timer for 500 cycles.¹¹ A histogram of the periods measured is shown in Figure 18, showing an average period of 1.911 seconds, with the width at half maximum 0.018 seconds.
Lastly, the photogate timer was positioned to capture the passage of a clock hand attached to the escape wheel arbor. If a time indicator were to be made, the best estimate of one cycle time of the hand would be (24 teeth)(1.911 seconds) = 45.86 seconds (i.e. imagine a clock face with ‘45.86 seconds’ at the top, instead of a 12). Next, the drive weight was configured to run the escapement for 90 minutes, while the cycle time of the minute hand was tracked with the photogate (based on the internal clock of a MacBook Air laptop). The accruing sequence cycle times of the hand were linearly correlated with the sequence generated by 45.86n, where n=0, 1, 2, 3, so a numerical regression was performed. This showed the escapement to gain about 4.5 milliseconds/second relative to the laptop clock, during the 90-minute run.

Conclusions
The complete escapement kit is shown in Figure 19, consisting of 20 total parts. Not shown are the yardstick, string, and drive and bob weights. Over two dozen escapement kits have been used by approximately 200 students both in the local and abroad versions of the class mentioned. When running, the arbor on the escape wheel turns once every 45 seconds, and will run for about 15 minutes before the weight hits the ground. Although not a simple or easy process, digital fabrication

Figure 16. Final escapement assembly.

Figure 18.
Distribution of
pendulum swing
times, as measured
by passing the
pendulum through
a photogate timer.
1.922

Occurence

Period (Seconds)

0

20

40

60

80

1.9 1.902 1.904 1.906 1.908 1.91 1.912 1.914 1.916 1.918 1.92

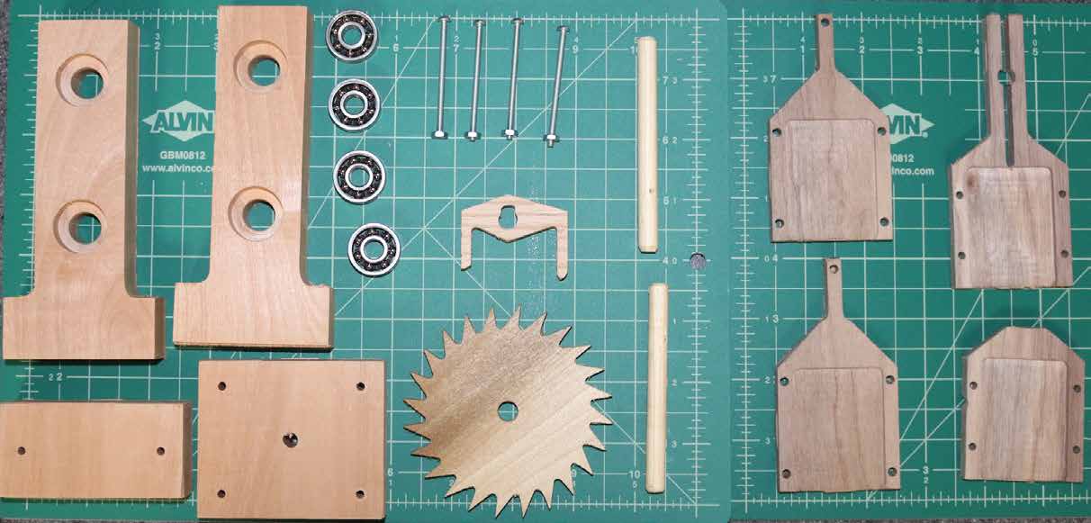
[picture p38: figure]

Figure 19. The full escapement kit, minus the yardstick pendulum, the drive and bob weights, and number 4 screws and nuts for the pendulum clamps.

About the Author
Tom Bensky is a Professor of Physics at California Polytechnic State University, in San Luis Obispo, California, USA. There, he teaches a wide variety of courses, ranging from introductory physics and astronomy, on up to advanced physics labs. His interest in horology began in 2008, when he was accepted to teach a course about the ‘longitude problem’ at his university’s summer London-study programme. He has since been back many times, taking students around the London area, showing them antiquarian clocks and navigation instruments.
Tom can be reached at tbensky@calpoly.edu

has helped enormously, as it is possible to instruct the CNC machine to cut the parts, after loading stock into the machine and zeroing the cutting tool. After assembling the parts, small adjustments will lead to a running escapement. I was not able to achieve such consistency using a scroll saw.
Students seem to engage in this ‘clock building’ activity quite happily. They spend the allotted time interacting in small groups, adjusting either aforementioned anchors 1 or 2, winding the weight and nudging the pendulum until it runs. Most can assemble the kit and have it working in under two hours, and when it runs for the first time, a happy emotional response is often heard. The kit seems to be doing its job in making for a gentle introduction to clock building, and the analysis and development trials outlined above provide much to discuss, as well as fodder for additional student assignments. The issue of a time indicator is still not obvious to some, in which case I ask them to think carefully about the motion of the escape wheel arbor. Our full activity involves them ‘calibrating’ the clock against their phones’ stopwatches and making a dial, complete with a hand attached to said arbor. Ongoing work includes developing a gear train that will drive a minute hand. Also, although somewhat difficult for the Shapeoko, a metal version of this escapement is planned.

Acknowledgements
Thank you Dr. Tom Gutierrez for his help with the Fourier transform, and the California Polytechnic International Centre, in particular Cari Vanderkar and Nayree Barnett for supporting the London ‘study abroad’ programme. Thank you also to the London-based Foundation for International Education for their hospitality. Lastly, we wish to express a sincere appreciation for the vibrant culture surrounding the history of timekeeping and navigation in England.

ENDNOTES

1. Justin Koullapis, ‘Gifts for Budding Horologists’, Horological Journal, vol. 157 (Dec 2015), p555.
2. Editors of Scroll Saw Woodworking & Crafts, Making Wooden Gear Clocks: 6 Cool Contraptions That Really Keep Time (Pennsylvania: Fox Chapel Publishing), 2016. This includes designs by Brian Law and Lisa Boyer.
3. Mike Flannery, ‘Clock and Watchmaking: Endangered Crafts?’, Horological Journal, vol. 160 (June 2018), pp262–263.
4. http://www.carbide3d.com/shapeoko
5. J. Rudolph, Make Your Own Paper Clock, 10th Anniversary Edition edn (William Morrow Paperbacks, 2001).
6. http://www.autodesk.com (accessed 18 April 2019)
7. http://www.amazon.com, search term ASIN #B06XTZJDCC (accessed 18 April 2019)
8. https://youtu.be/T28sGA597IE?t=4m30s, by user Clickspring (accessed 18 April 2019)
9. https://youtu.be/oZmjBCppGvk, by user phystv (accessed 18 April 2019)
10. W. Bensky, ‘Wi-Fi based Wireless sensors for data acquisition’, The Physics Teacher, vol.56 (Sep 2018), pp393–7. Available online at https://aapt.scitation.org/doi/10.1119/1.5051157
11. https://www.vernier.com/products/sensors/vpg-btd/ (accessed 18 April 2019)

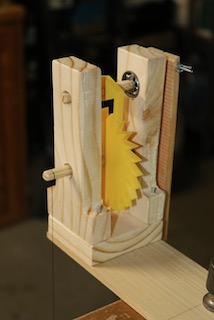
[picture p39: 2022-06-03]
Pics/escapement.jpeg

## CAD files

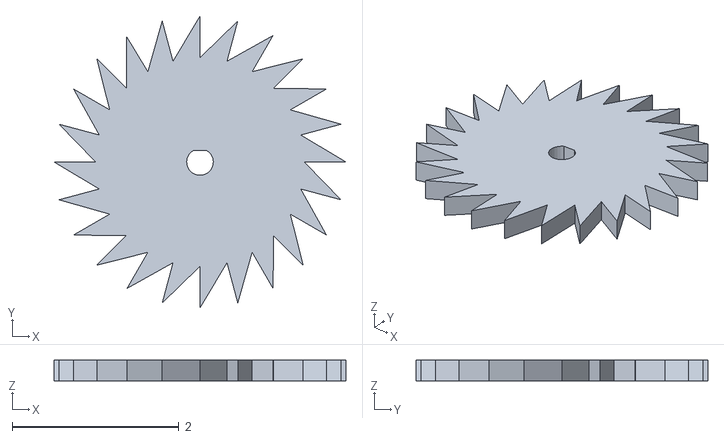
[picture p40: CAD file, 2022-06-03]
STL/24tooth.stl
3.50 x 3.50 x 0.25

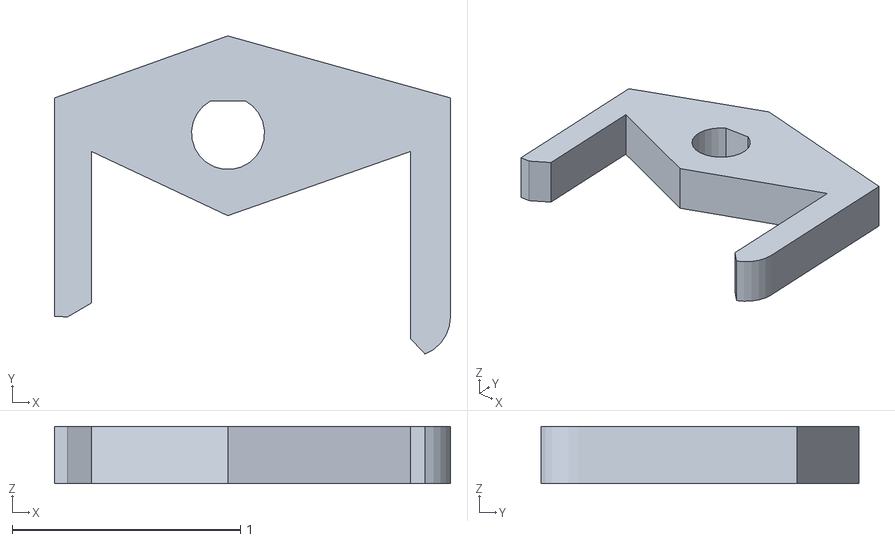
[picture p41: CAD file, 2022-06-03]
STL/anchor.stl
1.74 x 1.39 x 0.25

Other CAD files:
Cad/escape_and_anchor.dwg
Cad/cad_parts.dwg
